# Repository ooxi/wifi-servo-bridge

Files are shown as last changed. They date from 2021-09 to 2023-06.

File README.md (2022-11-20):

# Wifi Servo Bridge 

Sample [firmware](firmware/WifiServoBridge/WifiServoBridge.ino) and
[hardware](hardware/WifiServoBridge) showing of how to utilize ESP32 for driving
servo motors controlled over Wifi.

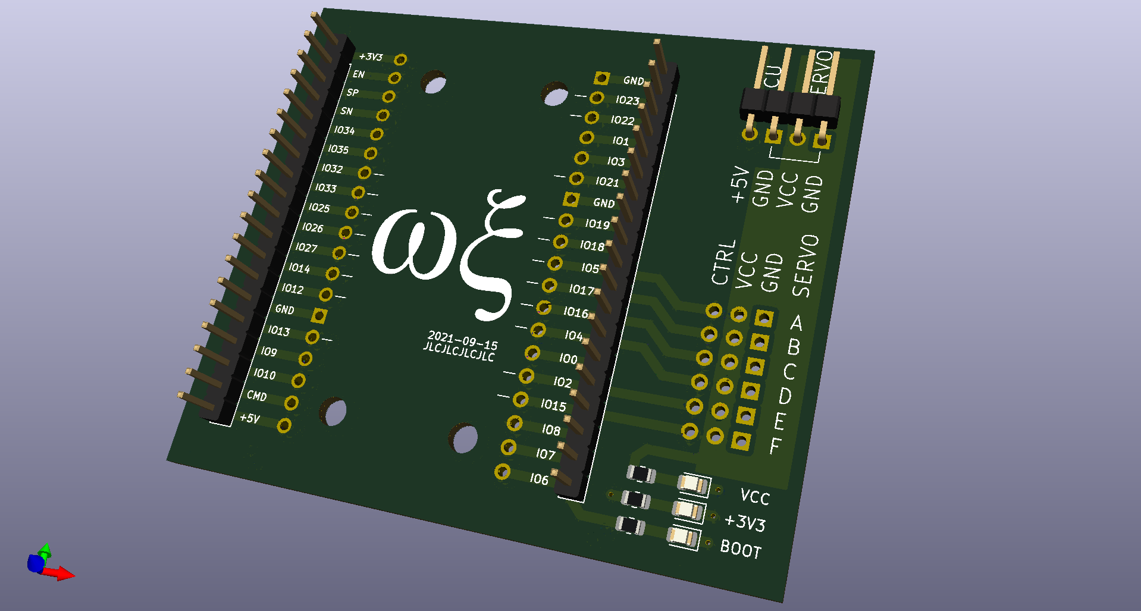
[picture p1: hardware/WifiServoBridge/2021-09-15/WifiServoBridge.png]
Wifi Servo Bridge 2021-09-15


## Quickstart

```
mc firmware make -C firmware
```

See also [dedicated firmware README](firmware/README.md)

## Usage

* Connect both MCU as well as Servo power to the Wifi Servo Bridge PCB
* Wait until the boot LED is no longer lit up. If the LED starts blinking fast,
  connecting to Wifi causes trouble
* Use the following commands to read and write servo positions. Replace
  `wifi-servo-bridge` with the Wifi Servo Bridge's actual IP (will be displayed
  on serial connection)

```bash
curl -X GET http://wifi-servo-bridge/v2/servo/A/	# Read angle of servo E
curl -X PUT http://wifi-servo-bridge/v2/servo/B/90	# Move servo B to angle 90°
curl -X PUT http://wifi-servo-bridge/v2/servo/E/180	# Move servo E to angle 180°
curl -X PUT http://wifi-servo-bridge/v2/servo/F/0	# Move servo F to angle 0°
```

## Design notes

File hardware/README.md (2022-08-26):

# Hardware Errata

## [WifiServoBridge/2021-09-15](WifiServoBridge/2021-09-15)

* `BOOT`-LED is connected to `GPIO6`, which internally is connected to the
  integrated SPI flash, thus unusable for status communication
* Current firmware thus uses `GPIO26` for status communication, which is not
  connected to an LED without a mod

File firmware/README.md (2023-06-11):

# ESP32 Servo

## Quickstart

```
mc firmware make 
mc firmware make upload
```

## FAQ

### How to check if ESP32 module itself is working property

A simple test to check whether the toolchain and your ESP32 module is working is
to upload a [Blinky][Blinky] sketch

```
mc firmware make FIRMWARE=Blinky upload
```

The debug LED connected to pin 23 should now be blinking

[Blinky]: https://github.com/ooxi/wifi-servo-bridge/blob/main/firmware/Blinky/Blinky.ino

### `serial.serialutil.SerialException: [Errno 13] could not open port /dev/ttyUSB0: [Errno 13] Permission denied: '/dev/ttyUSB0'`

* Check that your ESP32 is connected via `/dev/ttyUSB0` (you can change `TTY` in [Makefile][Makefile])
* Check that your user has read/write permissions on `/dev/ttyUSB0`
* Check that the `/dev/ttyUSB0` device is forwarded to the docker container via `--device /dev/ttyUSB0`

### `A fatal error occurred: Failed to connect to ESP32: Invalid head of packet (0x1B)`

Looks like the device is not automatically entering programming mode. As soon as
you start seeing

```
Connecting........_____..
```

try holding the «BOOT» or «PROG» button and press the «RST» or «EN» button. The
ESP32 should enter bootloader mode and accept the firmware coming in.

### How to switch WifiServoBridge between Access Point and Client behaviour

```
mc firmware make FIRMWARE=WifiServoBridge BUILD_EXTRA_FLAGS=-DWIFI_SERVO_BRIDGE_BEHAVE_AS_ACCESS_POINT
mc firmware make FIRMWARE=WifiServoBridge BUILD_EXTRA_FLAGS=-DWIFI_SERVO_BRIDGE_BEHAVE_AS_CLIENT
```

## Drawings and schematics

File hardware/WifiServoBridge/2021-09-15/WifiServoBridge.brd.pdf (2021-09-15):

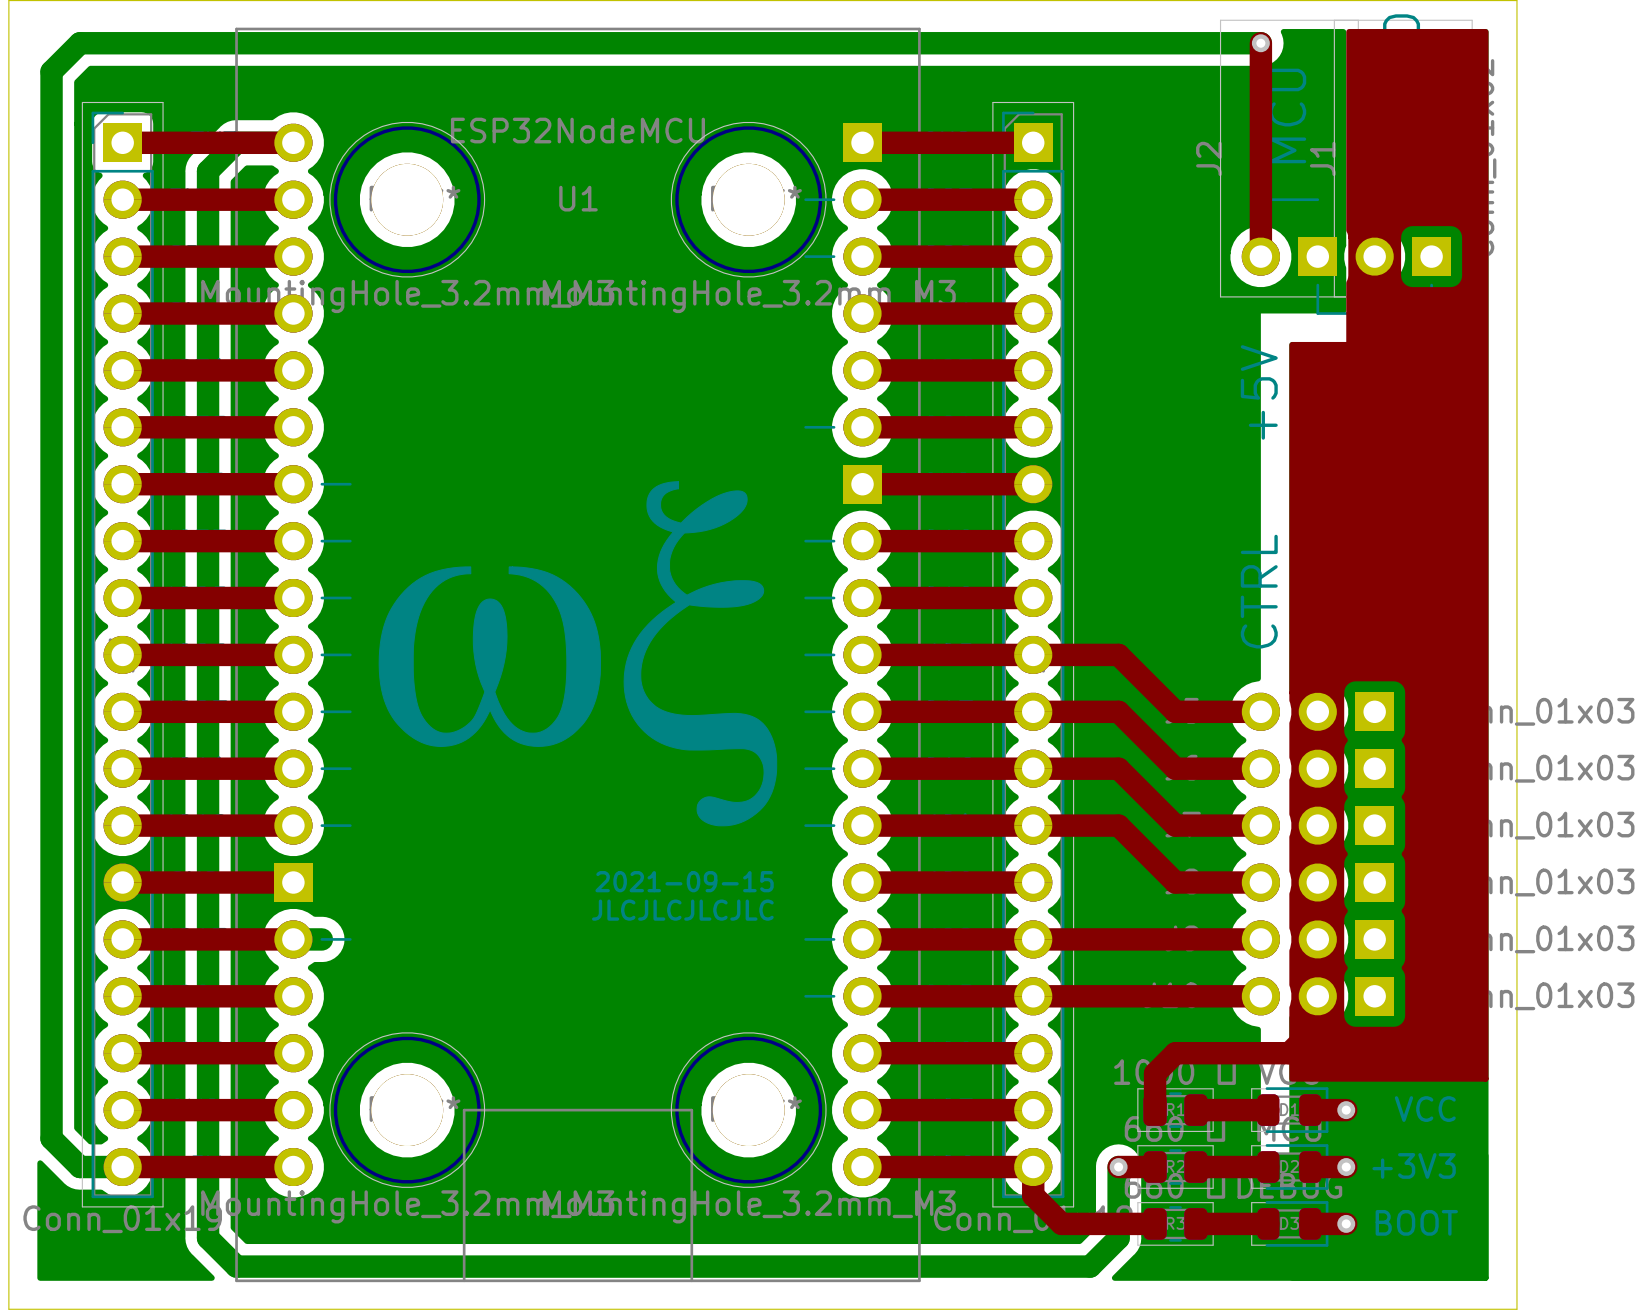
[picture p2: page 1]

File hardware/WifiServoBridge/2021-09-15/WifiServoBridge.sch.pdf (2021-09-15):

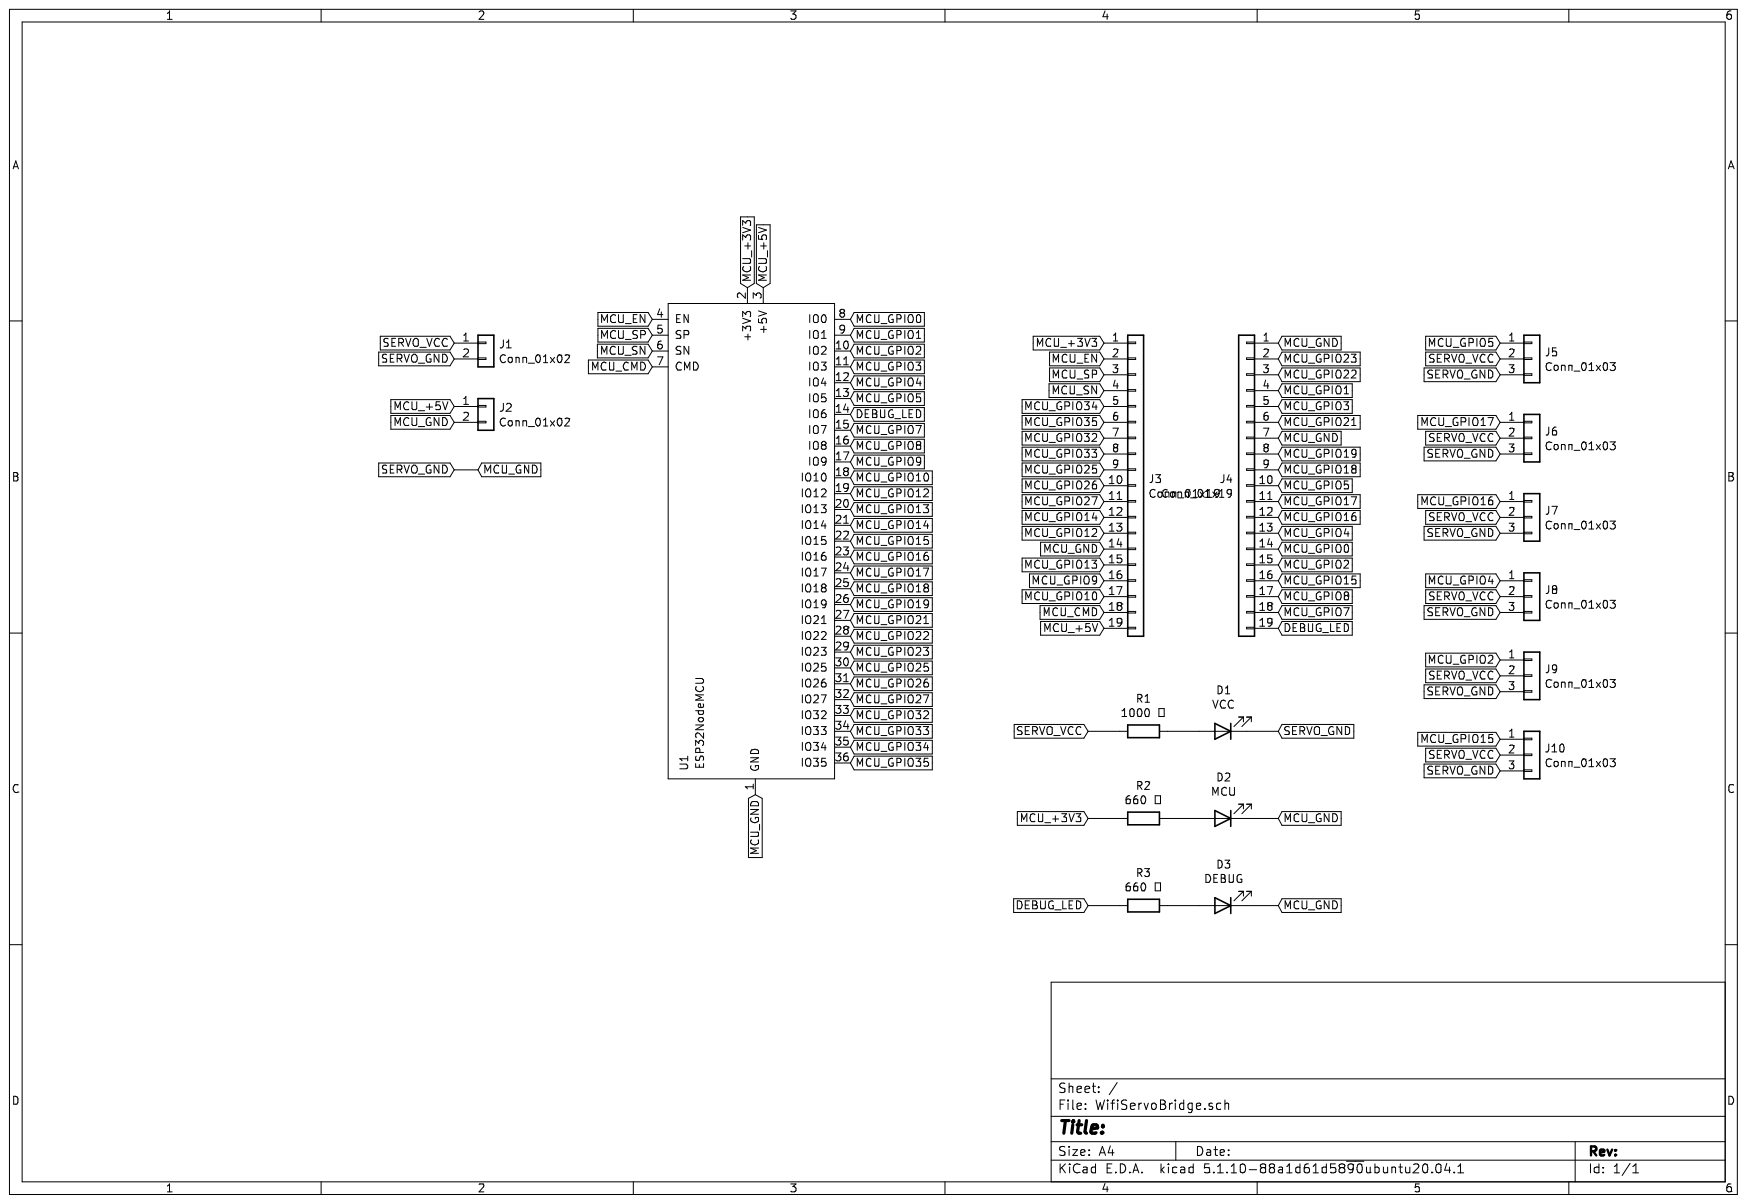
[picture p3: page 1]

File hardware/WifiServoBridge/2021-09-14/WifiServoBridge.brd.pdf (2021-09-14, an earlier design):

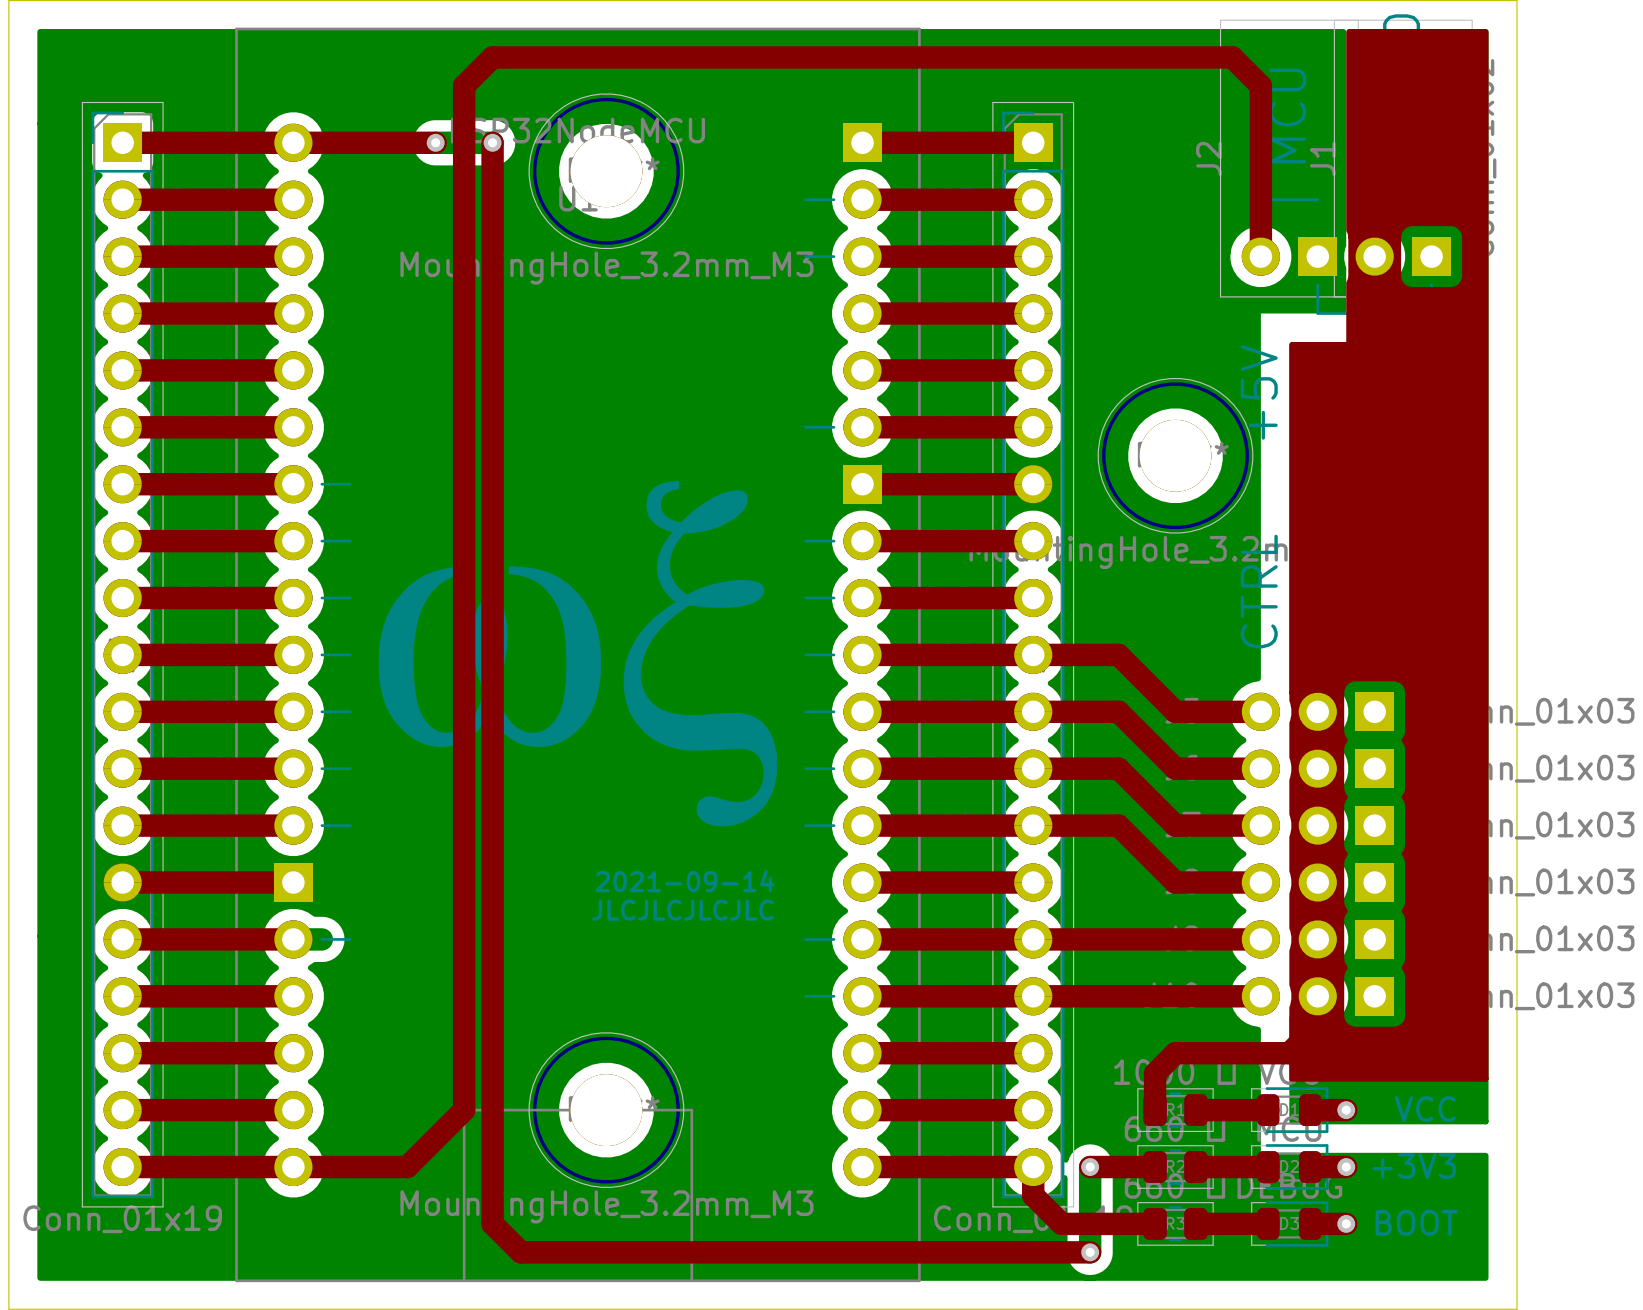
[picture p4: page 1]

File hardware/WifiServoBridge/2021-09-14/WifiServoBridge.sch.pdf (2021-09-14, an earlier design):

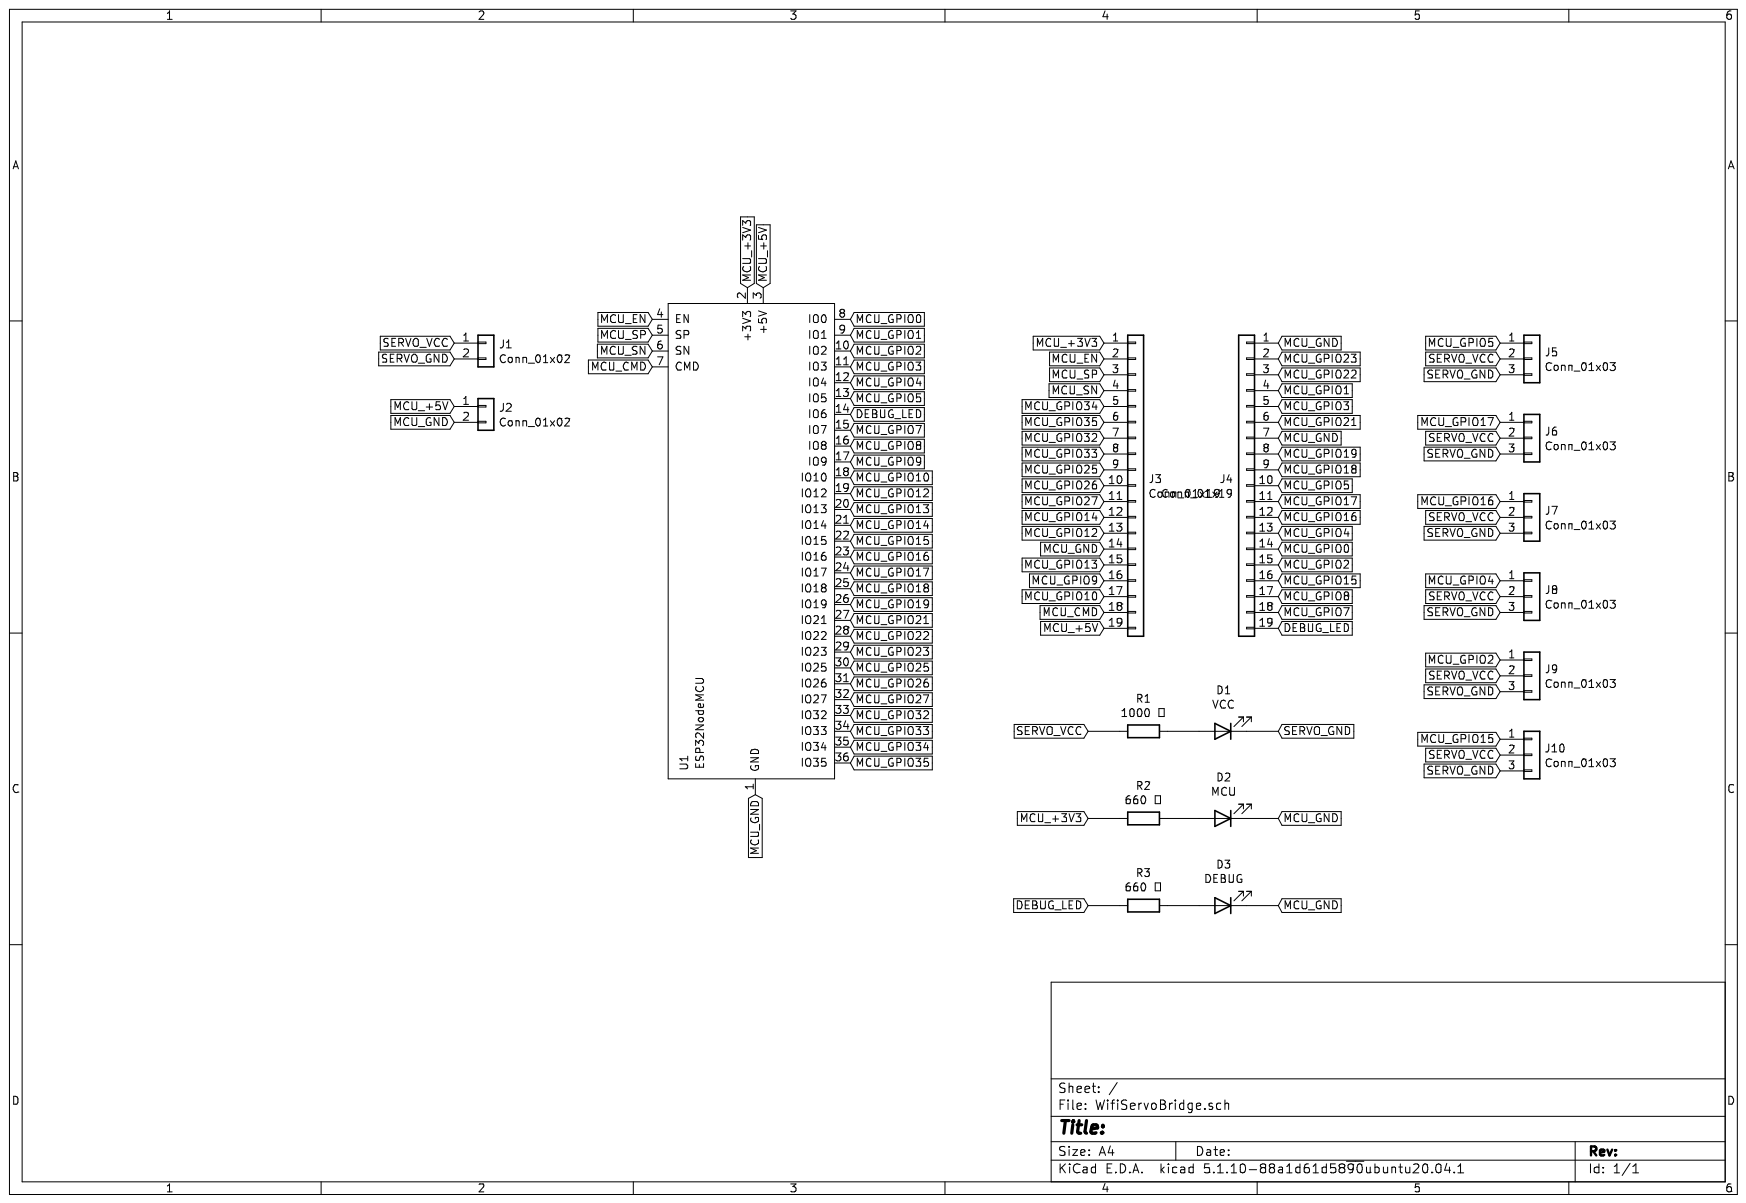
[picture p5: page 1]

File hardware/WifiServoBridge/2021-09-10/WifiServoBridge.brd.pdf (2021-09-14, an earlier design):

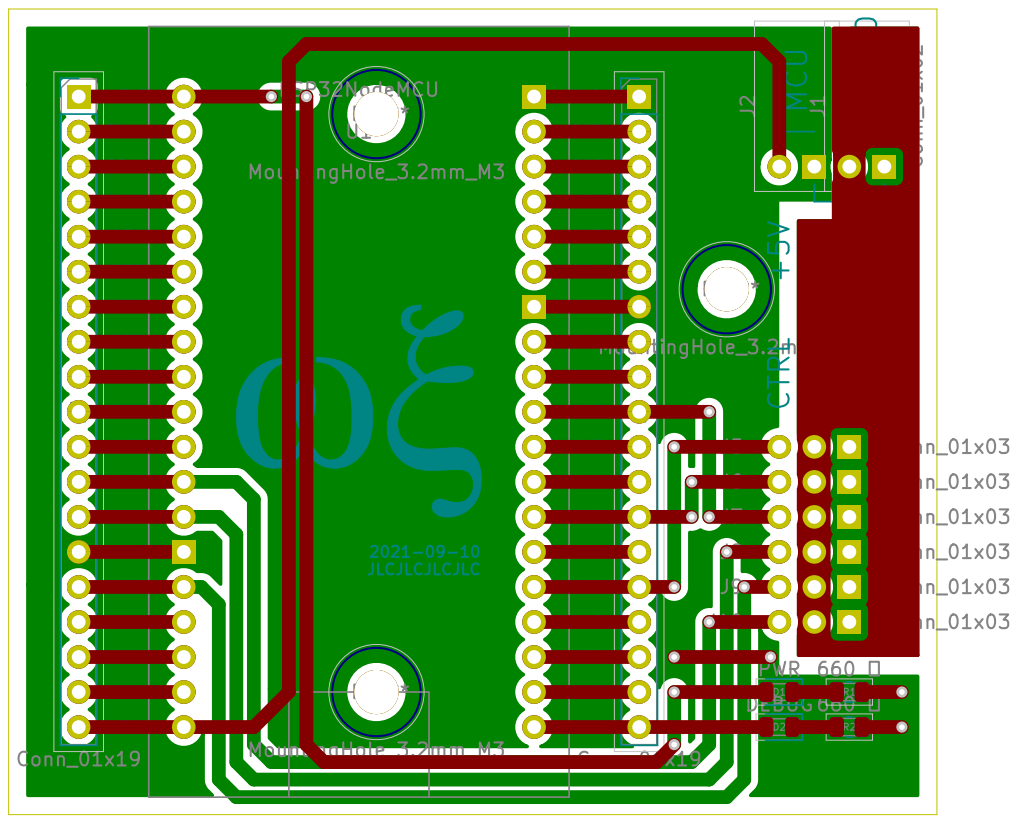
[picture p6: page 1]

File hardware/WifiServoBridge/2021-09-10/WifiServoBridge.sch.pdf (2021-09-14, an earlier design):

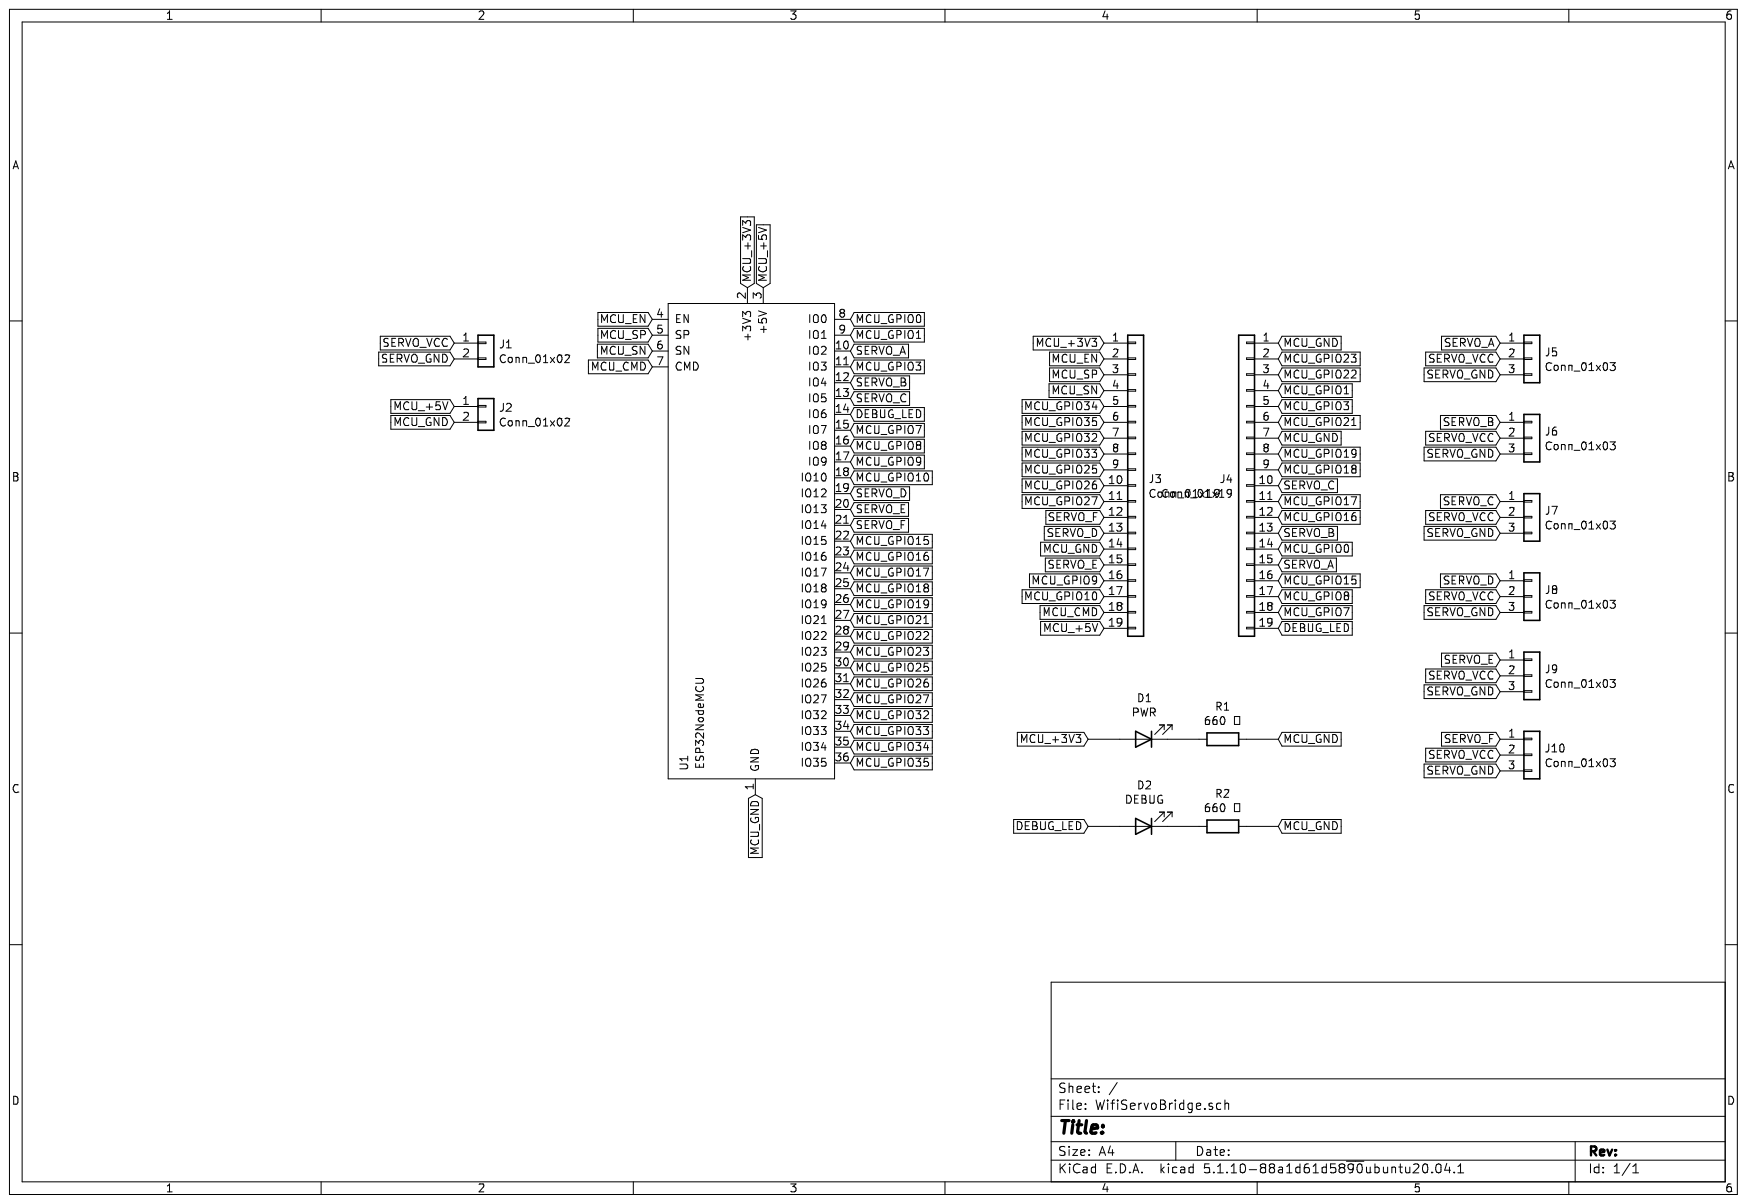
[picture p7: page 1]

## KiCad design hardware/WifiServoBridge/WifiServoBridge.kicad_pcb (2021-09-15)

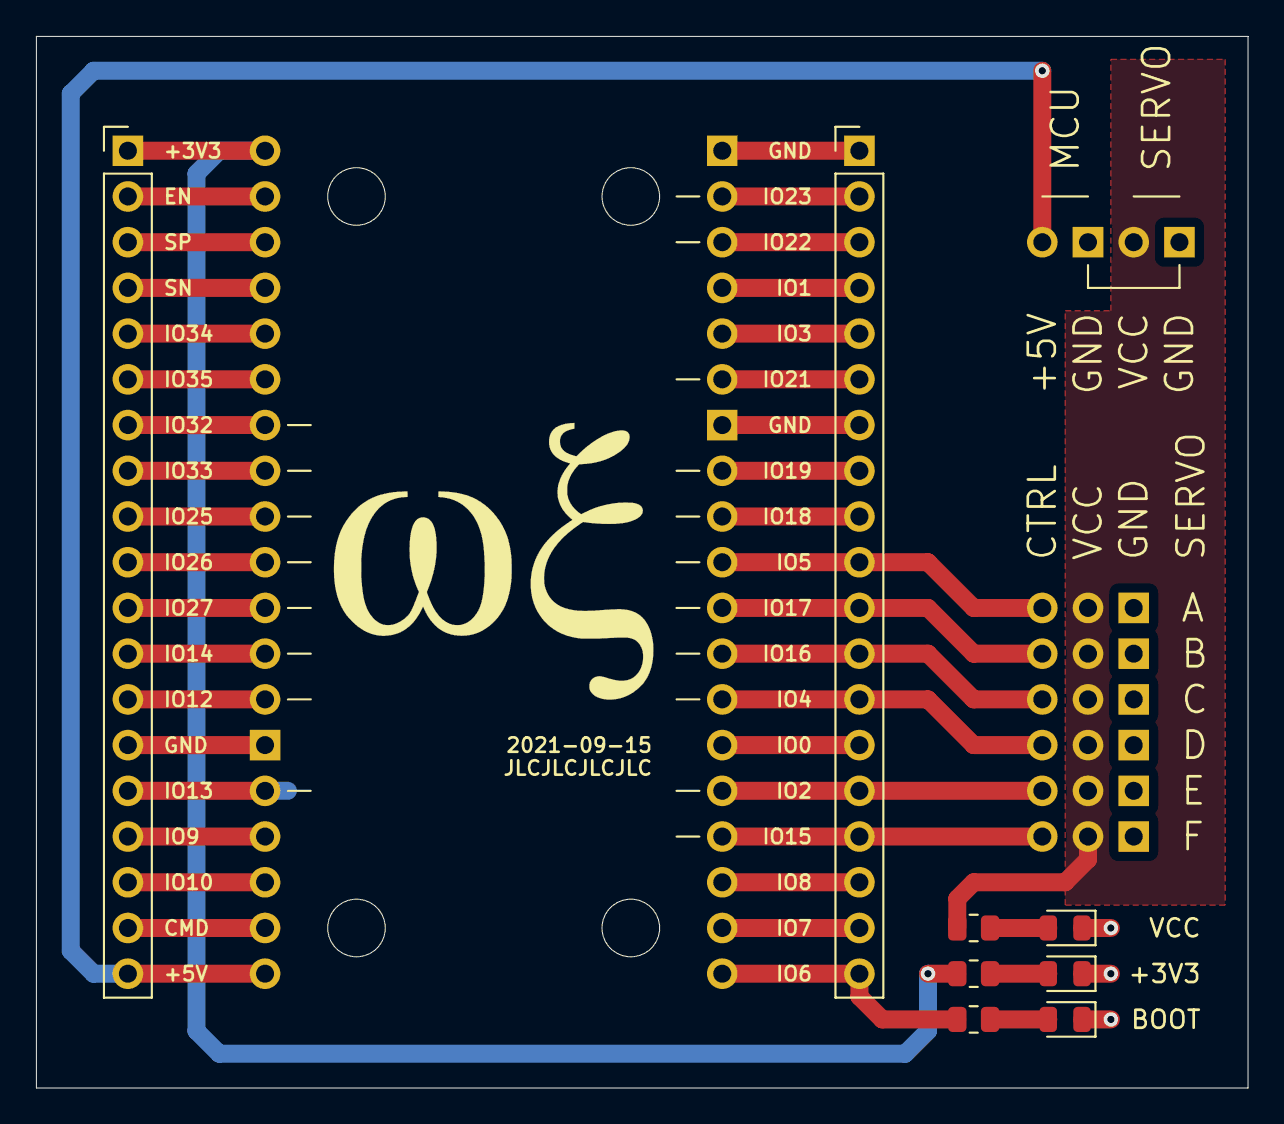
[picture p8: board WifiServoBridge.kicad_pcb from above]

Board: 2 copper layers, 67.3 x 58.4 mm, 17 parts (0 on the bottom side), 40 nets.

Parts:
D1: VCC; LED_0805_2012Metric
D2: MCU; LED_0805_2012Metric
D3: DEBUG; LED_0805_2012Metric
J1, J2: Conn_01x02; Power Connector
J3, J4: Conn_01x19; PinHeader_1x19_P2.54mm_Vertical
J5, J6, J7, J8, J9, J10: Conn_01x03; Servo Connector
R1: 1000 Ω; R_0805_2012Metric
R2, R3: 660 Ω; R_0805_2012Metric
U1: ESP32NodeMCU; ESP32 NodeMCU

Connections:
DEBUG_LED: J4.19, R3.2, U1.14
MCU_+3V3: J3.1, R2.2, U1.2
MCU_+5V: J2.1, J3.19, U1.3
MCU_CMD: J3.18, U1.7
MCU_EN: J3.2, U1.4
MCU_GND: D1.1, D2.1, D3.1, J1.2, J2.2, J3.14, J4.1, J4.7, J5.3, J6.3, J7.3, J8.3, J9.3, J10.3, U1.1
MCU_GPIO0: J4.14, U1.8
MCU_GPIO1: J4.4, U1.9
MCU_GPIO2: J4.15, J9.1, U1.10
MCU_GPIO3: J4.5, U1.11
MCU_GPIO4: J4.13, J8.1, U1.12
MCU_GPIO5: J4.10, J5.1, U1.13
MCU_GPIO7: J4.18, U1.15
MCU_GPIO8: J4.17, U1.16
MCU_GPIO9: J3.16, U1.17
MCU_GPIO10: J3.17, U1.18
MCU_GPIO12: J3.13, U1.19
MCU_GPIO13: J3.15, U1.20
MCU_GPIO14: J3.12, U1.21
MCU_GPIO15: J4.16, J10.1, U1.22
MCU_GPIO16: J4.12, J7.1, U1.23
MCU_GPIO17: J4.11, J6.1, U1.24
MCU_GPIO18: J4.9, U1.25
MCU_GPIO19: J4.8, U1.26
MCU_GPIO21: J4.6, U1.27
MCU_GPIO22: J4.3, U1.28
MCU_GPIO23: J4.2, U1.29
MCU_GPIO25: J3.9, U1.30
MCU_GPIO26: J3.10, U1.31
MCU_GPIO27: J3.11, U1.32
MCU_GPIO32: J3.7, U1.33
MCU_GPIO33: J3.8, U1.34
MCU_GPIO34: J3.5, U1.35
MCU_GPIO35: J3.6, U1.36
MCU_SN: J3.4, U1.6
MCU_SP: J3.3, U1.5
unnamed: D1.2, R1.1
unnamed: D2.2, R2.1
unnamed: D3.2, R3.1
SERVO_VCC: J1.1, J5.2, J6.2, J7.2, J8.2, J9.2, J10.2, R1.2

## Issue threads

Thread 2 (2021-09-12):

Add led silk screens

ooxi, 2021-09-12:
* Servo power indication
* MCU power indication
* Boot indication

ooxi, 2021-09-14:
Added silk screen labels for all LEDs in 142db1b77f29157905fcfea2cd0ca7a744e9db32

Closed 2021-09-14.

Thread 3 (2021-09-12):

Replace 0-5 with A-F in firmware

ooxi, 2021-09-12:
Servos should be identified by their silk screen labels (`A` - `F` instead of `0` - `5`)

ooxi, 2021-09-30:
Implemented in 46e71e1d713f3fab242266fee547800e490c3627

Closed 2021-09-30.

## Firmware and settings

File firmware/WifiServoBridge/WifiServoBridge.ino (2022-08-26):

// SPDX-License-Identifier: Zlib
#include <Arduino.h>
#include <ESP32Servo.h>
#include <WebServer.h>
#include <WiFi.h>

/* @warning `UriBraces.h' should be available through espressif's WebServer
 *     library but cannot be found
 */
#include "vendor/optional.hpp"
#include "vendor/UriBraces.h"

#include <array>
#include <cstdint>
#include <string>
#include <utility>


struct ServoConfig {
	char const* name;
	std::uint8_t pin;
};

static std::string const WIFI_SSID{"********"};		// Replace with your Wifi SSID
static std::string const WIFI_PASSWORD{"********"};	// Replace with your Wifi password
constexpr std::uint16_t WIFI_PORT{80};

constexpr std::uint8_t PIN_DEBUG_LED{23};
constexpr std::array<ServoConfig, 6> PIN_SERVO{
	ServoConfig{"A", 5},
	ServoConfig{"B", 17},
	ServoConfig{"C", 16},
	ServoConfig{"D", 4},
	ServoConfig{"E", 2},
	ServoConfig{"F", 15},
};


static WebServer httpd{WIFI_PORT};
static std::array<Servo, PIN_SERVO.size()> servos;


/**
 * Tells the user a non recoverable error has occured and halts further
 * processing
 */
static void loopError(char const* message) {
	Serial.println(message);
	httpd.stop();

	for (;;) {
		::digitalWrite(PIN_DEBUG_LED, LOW);
		::delay(500);
		::digitalWrite(PIN_DEBUG_LED, HIGH);
		::delay(500);
	}
}


/**
 * Provides a UI for human debugging
 *
 * GET /
 */
static void handleGetRoot() {
	constexpr auto HTTP_OK{200};
	httpd.send(HTTP_OK, "text/plain", "WifiServoBridge\n");
}


/**
 * @return Index of servo by name iff name is valid
 */
static tl::optional<std::size_t> getServoIdxFromName(String const& expectedName) {
	for (std::size_t idx = 0; idx < PIN_SERVO.size(); ++idx) {
		String const actualName{PIN_SERVO.at(idx).name};

		if (actualName.equals(expectedName)) {
			return idx;
		}
	}

	return tl::nullopt;
}


/**
 * Reads back the servo position last set by this firmware
 *
 * GET /v2/servo/$servo/
 *
 * @param $servo Servo name to read position from
 *
 * @warning Might _not_ be the physical servo position!
 */
static void handleGetServo() {
	constexpr auto HTTP_OK{200};
	constexpr auto HTTP_BAD_REQUEST{400};

	auto const servoIdx = getServoIdxFromName(httpd.pathArg(0));

	if (!servoIdx.has_value()) {
		httpd.send(HTTP_BAD_REQUEST, "text/plain", "Invalid servo name\n");
		return;
	}

	auto const position = servos.at(servoIdx.value()).read();
	httpd.send(HTTP_OK, "application/json", String(position));
}


/**
 * Move servo to angle
 *
 * PUT /v2/servo/$servo/$angle
 *
 * @param $servo Servo name to write position to
 * @param $angle Desired server angle (0 - 180)
 */
static void handlePutServo() {
	constexpr auto HTTP_OK{200};
	constexpr auto HTTP_BAD_REQUEST{400};

	auto const servoIdx = getServoIdxFromName(httpd.pathArg(0));
	auto const angle = httpd.pathArg(1).toInt();

	if (!servoIdx.has_value()) {
		httpd.send(HTTP_BAD_REQUEST, "text/plain", "Invalid servo name\n");
		return;
	}

	if ((angle < 0) || (angle > 180)) {
		httpd.send(HTTP_BAD_REQUEST, "text/plain", "Invalid angle\n");
		return;
	}

	servos.at(servoIdx.value()).write(angle);
	auto const position = servos.at(servoIdx.value()).read();
	httpd.send(HTTP_OK, "application/json", String(position));
}


void setup() {

	/* Earliest signal that module is alive
	 */
	::pinMode(PIN_DEBUG_LED, OUTPUT);
	::digitalWrite(PIN_DEBUG_LED, HIGH);


	/* Open serial interface in order to be able to communicate debug
	 * messages
	 */
	Serial.begin(115200);
	Serial.println("WifiServoBridge");


	/* Initialize all servos by attaching them to their desired pins
	 */
	if (PIN_SERVO.size() != servos.size()) {
		loopError("The number of servos must match the number of servo pins");
		return;
	}

	for (auto i = 0; i < servos.size(); ++i) {
		auto const result = servos.at(i).attach(PIN_SERVO.at(i).pin);

		if (0 == result) {
			loopError("Failed attaching servo to pin");
			return;
		}
	}


	/* Reset servo position
	 */
	for (Servo& servo : servos) {
		servo.write(0);
	}


#if defined(WIFI_SERVO_BRIDGE_BEHAVE_AS_ACCESS_POINT) && !defined(WIFI_SERVO_BRIDGE_BEHAVE_AS_CLIENT)

	/* Create a Wifi Access Point
	 */
	Serial.println(("Creating AP " + WIFI_SSID).c_str());
	WiFi.softAP(WIFI_SSID.c_str(), WIFI_PASSWORD.c_str());

	Serial.print("WiFi connected @ ");
	Serial.println(WiFi.softAPIP());

#elif defined(WIFI_SERVO_BRIDGE_BEHAVE_AS_CLIENT) && !defined(WIFI_SERVO_BRIDGE_BEHAVE_AS_ACCESS_POINT)

	/* Connect to specified Wifi
	 */
	Serial.println(("Connecting to " + WIFI_SSID).c_str());
	WiFi.begin(WIFI_SSID.c_str(), WIFI_PASSWORD.c_str());

	while (WiFi.status() != WL_CONNECTED) {
		::digitalWrite(PIN_DEBUG_LED, LOW);
		::delay(250);
		::digitalWrite(PIN_DEBUG_LED, HIGH);
		::delay(250);
		Serial.print(".");
	}

	Serial.println("");
	Serial.print("WiFi connected @ ");
	Serial.println(WiFi.localIP());
#else
	#error WifiServoBridge must behave either as access point or as client
#endif


	/* Initialize HTTP server
	 */
	httpd.begin();

	httpd.on("/", HTTP_GET, handleGetRoot);
	httpd.on(UriBraces{"/v2/servo/{}/"}, HTTP_GET, handleGetServo);
	httpd.on(UriBraces{"/v2/servo/{}/{}"}, HTTP_PUT, handlePutServo);


	/* Signal the user that the application is up and running
	 */
	::digitalWrite(PIN_DEBUG_LED, LOW);
}


void loop() {
	httpd.handleClient();

	/* Allow the CPU to switch to other tasks
	 *
	 * @see https://github.com/espressif/arduino-esp32/blob/f7fc8ab37714efc1e00ef640a3e4f51ca647fac5/libraries/WebServer/examples/HelloServer/HelloServer.ino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
	 */
	::delay(2);
}

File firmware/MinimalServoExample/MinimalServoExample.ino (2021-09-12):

// SPDX-License-Identifier: Zlib
#include <Arduino.h>
#include <ESP32Servo.h>

#include <array>
#include <cstdint>


constexpr std::uint8_t PIN_DEBUG_LED{23};
constexpr std::array<std::uint8_t, 6> PIN_SERVO{2, 4, 12, 13, 14, 15};


static std::array<Servo, PIN_SERVO.size()> servo;


void setup() {

	/* Open serial interface in order to be able to communicate debug
	 * messages
	 */
	Serial.begin(115200);
	Serial.println("WifiServoBridge");


	/* Initialize all servos by attaching them to their desired pins
	 */
	if (PIN_SERVO.size() != servo.size()) {
		loopError("The number of servos must match the number of servo pins");
		return;
	}

	for (auto i = 0; i < servo.size(); ++i) {
		auto const result = servo.at(i).attach(PIN_SERVO.at(i));

		if (0 == result) {
			loopError("Failed attaching servo to pin");
			return;
		}
	}


	/* Signal the user that the application is up and running
	 */
	::pinMode(PIN_DEBUG_LED, OUTPUT);
	::digitalWrite(PIN_DEBUG_LED, HIGH);


	/* Test servos by setting them to a known rotation
	 */
	servo.at(0).write(0);
	servo.at(1).write(36);
	servo.at(2).write(72);
	servo.at(3).write(108);
	servo.at(4).write(144);
	servo.at(5).write(180);
}


void loop() {
}


static void loopError(char const* message) {
	Serial.println(message);
	for (;;) {
		::digitalWrite(PIN_DEBUG_LED, HIGH);
		::delay(500);
		::digitalWrite(PIN_DEBUG_LED, LOW);
		::delay(500);
	}
}

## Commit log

2021-09-12 Initial development
    Setup of isolated development environment based on arduino-cli finished.
2021-09-12 Simple servo example
    Provided a sketch which sets the servos to a well known position for manual debugging and as a starting point for modifications which do not need the Wifi part.
2021-09-12 Pin esp32 core version
2021-09-12 Wifi Servo Bridge implementation
2021-09-12 Wifi Servo Bridge Hardware 2021-09-10
    Mounting hole position is not ideal, however I didn't want to increase the PCB size.
    [WifiServoBridge-B_Cu.gbr, WifiServoBridge-B_Mask.gbr, WifiServoBridge-B_Paste.gbr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]
2021-09-14 Simplified PWM routing
    Used the physically closed PWM capable pins.
    [WifiServoBridge.kicad_pcb, WifiServoBridge.sch]
2021-09-14 Add VCC LED and silkscreen labels
    Closes issue #1 and issue #2
    [WifiServoBridge-B_Cu.gbr, WifiServoBridge-B_Mask.gbr, WifiServoBridge-B_Paste.gbr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]
2021-09-14 Update GPIO ports to reflect simplified routing
    In order to simplify the routing, physically close PWM capable pins were chosen in 2010491c43cab9126c8b33ba7750f66a60a62bff. This change reflects the physical properties of board 2021-10-14 in firmwa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
2021-09-15 `MCU_GND' and `SERVO_GND' must be connected on board
    Since the serve control line is relative to the servo ground potential, MCU and servo ground must be on the same potential.
    [WifiServoBridge.kicad_pcb, WifiServoBridge.sch]
2021-09-15 Improved optics by routing +5V as well as +3V3 on bottom
    [WifiServoBridge-B_Cu.gbr, WifiServoBridge-B_Mask.gbr, WifiServoBridge-B_Paste.gbr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]
2021-09-15 Production data of PCB order
2021-09-15 Drill files have to be exported separately from plotting Gerber
    [WifiServoBridge-NPTH.drl, WifiServoBridge-PTH.drl]
2021-09-30 API v2
    Replaced numeric servo index by textual servo name.
    Warning: Firmware not yet verified on hardware
    [WifiServoBridge.ino]
2022-08-26 Update ESP32Servo to 0.11.0
2022-08-26 WifiServoBrdige Access Point support
    Using a compile time switch, one can now change the behaviour of WifiServoBridge from Wifi Client to Wifi Access Point
